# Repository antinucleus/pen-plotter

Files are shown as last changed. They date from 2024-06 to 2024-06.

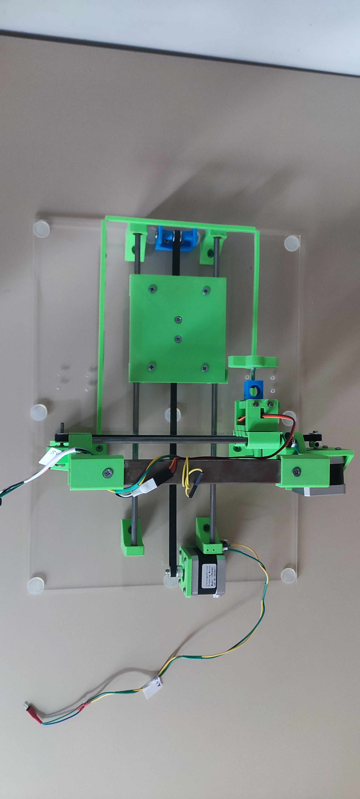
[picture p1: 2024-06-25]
Mechanical Design/Media/Realized Machine Photos/top.jpg

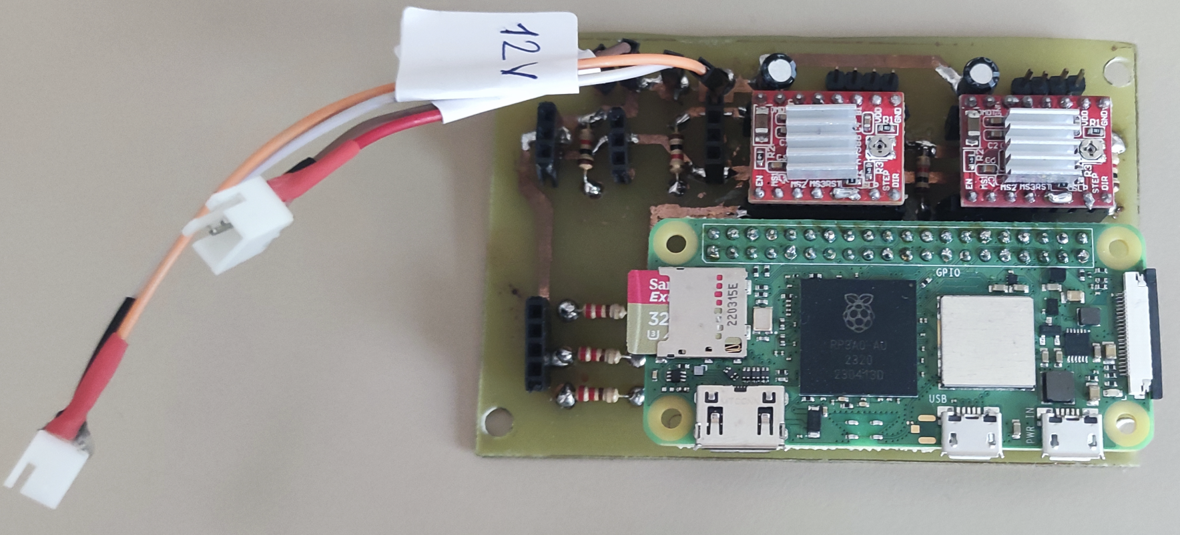
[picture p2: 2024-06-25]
Electrical Design/Media/Realized Photos/realized.png

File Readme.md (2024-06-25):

# GRADUATION THESIS

This repository explains the project i made for my mechatronics engineering graduation thesis. This README file contains general project information. For detailed information, please refer to the mechanical, electronic, and software folders.

## Table of Contents

- [Introduction](#introduction)
- [Demo](#demo)
- [Mehatronic System Design Report](#msd-report)
- [Final Report](#final-report)
- [Contact](#contact)

## Introduction

The graduation thesis project is a pen plotter machine. All mechanical, electronic, and software sections of this project have been created from scratch. Each section has its own folder. You can see the features and known shortcomings of the project in the README file of each section. For details, you can review the reports in the `reports` folder located in the root directory.

## Demo

<h4 align="center">
  Watch Demo Video on Youtube
</h4>

Watch the video (https://www.youtube.com/watch?v=F13d5m1M79A)

## MSD Report

You can access the `mechatonic system design` report from the link below.

MSD Report Link: [Mechatronic System Design Report](https://github.com/antinucleus/pen-plotter/blob/main/Reports/MST-Report.pdf)

## Final Report

Due to the time problem during the project, there are some missing and unformatted sections in the final report. You can access the `final report` from the link below.

Final Report Link: [Final Report](https://github.com/antinucleus/pen-plotter/blob/main/Reports/Final-Report.pdf)

## Contact

Ömer Faruk Bağcı - [omerfarukbagci@antinucleus.dev](mailto:omerfarukbagci@antinucleus.dev)

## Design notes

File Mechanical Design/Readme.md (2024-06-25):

# MECHANICAL DESIGN

You can find the STL files in the STL folder in this directory. For details, you can review the reports in the `reports` folder located in the root directory.

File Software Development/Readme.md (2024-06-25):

# SOFTWARE DEVELOPMENT

In this section, you can examine how the software side of the project works.

## Table of Contents

- [Introduction](#introduction)
- [How It Works](#how-it-works)

## How It Works ?

The entire control of the plotter machine is managed by a **Raspberry Pi Zero 2W** board and a mobile application that controls it. Two main programs run on the Raspberry Pi: the `server` and the `hardware control program (the hardware control program is named Raspi Hardware Controller)`. These programs are run by linux services that start themselves after the **Raspberry Pi OS** boots.

### Raspberry Pi Zero 2W Side

The folder structure for the two main programs running on the Raspberry Pi is as follows:

```bash
|___ PlotterController
     |
     |___ plotter-express-server
     |
     |___ embedded
```

- The `plotter-express-server` directory contains the server program that facilitates communication between the `mobile application` and the `Raspi Hardware Controller`. This server is written with `express.js`.

- The `embedded` directory contains the program written in `cpp` that controls the hardware (stepper motors, servo motors, limit switches...) which I have named `Raspi Hardware Controller`.

#### Linux Services

The above two programs are automatically started by Linux services after the **Raspberry Pi OS** (installed on the Raspberry Pi Zero 2W) boots. These Linux services are as follows:

- The following linux service runs the server written in `express.js`.

```sh
[Unit]
Description=Server Controller Service
After=multi-user.target

[Service]
Type=idle
ExecStart=/usr/bin/node /home/oxygen/Desktop/PlotterController/plotter-express-server/index.js

[Install]
WantedBy=multi-user.target
```

- The other Linux service runs the `Raspi Hardware Controller`.

```sh
[Unit]
Description=Raspi Hardware Controller
After=multi-user.target

[Service]
Type=idle
ExecStart=/home/oxygen/Desktop/PlotterController/embedded/run

[Install]
WantedBy=multi-user.target
```

#### Server

Server program project link: https://github.com/antinucleus/plotter-express-server

#### Hardware Controller Program

Raspi hardware controller project link: https://github.com/antinucleus/plotter-embedded-controller

### Mobile Application Side

The mobile application is built with `expo`. With the mobile application, the plotter machine can be used in manual mode or to print desired image files. You can click on the following link to access the mobile application project.

Mobile application project link: https://github.com/antinucleus/plotter-mobile-application

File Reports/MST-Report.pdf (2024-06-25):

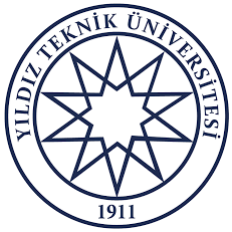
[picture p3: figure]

YILDIZ TECHNICAL UNIVERSITY

PEN PLOTTER

Ömer Faruk Bağcı

MECHATRONICS SYSTEM DESIGN REPORT

Project Advisor: Assoc. Prof. Haydar Livatyalı

ISTANBUL, 2023

Pen Plotter | Rev 2.1

CONTENTS

REVISION HISTORY | V

REVISION HISTORY

Date | Rev. No | Definition | Author(s)
23/12/2023 | 1.0 | Report Beginning | Ömer Faruk Bağcı
24/12/2023 | 1.1 | Mechanical Design and Torque Calculation was Added | Ömer Faruk Bağcı
25/12/2023 | 1.2 | Abstract, Project Definition, Aim, Scope, Literature Analysis was Added. | Ömer Faruk Bağcı
26/12/2023 | 1.3 | Power Consumption Calculation, Software was Added | Ömer Faruk Bağcı
27/12/2023 | 1.4 | Sensors, Project Management, Technical Requirements Analysis was Added. | Ömer Faruk Bağcı
28/12/2023 | 1.5 | The Report was Edited Together According to Its Integrity. | Ömer Faruk Bağcı
30/12/2023 | 1.6 | Content, Figure List, Table List was Created. Report Page Layout was Edited. | Ömer Faruk Bağcı
31/12/2023 | 1.7 | Motor Selection was Added | Ömer Faruk Bağcı
02/01/2024 | 1.8 | Equations were Named. | Ömer Faruk Bağcı
05/01/2024 | 2.0 | Final Preliminary Report was Completed. | Ömer Faruk Bağcı
11/01/2024 | 2.1 | Changed Titles and Typos were Fixed. | Ömer Faruk Bağcı

SYMBOL LIST

a: Acceleration

W: Weigℎt

N: Newton

Amps: Amper × Second

V: Volt

A: Amper

ℎ: ℎour

Wℎ: Watt × Hour

π: 3.14

LIST OF FIGURES

LIST OF TABLES

ABSTRACT

Ink or laser for transferring digital drawings or writings onto a sheet of paper printers are

used. In some cases, this information is not stored on paper or in other ways. It must be

transferred to the surface. In cartography, technical training is required to draw detailed maps

for drawing or drawing electronic circuits on PCBs (Printed Circuit Boards) Ink or laser

printers are not useful when necessary. For example, to transfer an electronic circuit drawing

onto a PCB, ink or laser It must be printed on wax paper using a printer. Then, the circuit

drawing on paper is transferred to the PCB using heat. However, while the drawing is

transferred onto the PCB using heat, the ink in some areas may not completely transfer to the

PCB or the paper may tear. A pen plotter device can be used to solve the problems in this

example. With the pen plotter device, drawings can be made on different surfaces easily and

with high precision transferable.

There are two types of plotter machines. One of them is electrostatic plotter another one is

pen plotter. We decided to design pen plotter becuase of our project requirements. Raspberry

pi zero 2w single board computer will be used in plotter motion control and receiving data

that will be plotted. In the motor motion side, Nema 17 step motor and Sg90 servo motor will

be used. Our machine will be controlled with mobile or desktop application remotely. For

these applications we use JavaScript and TypeScript languages. On the single board computer

side we use JavaScript and C languages.

1. PROJECT DESCRIPTION

This project delves into the development and implementation of a Raspberry Pi Zero 2W-

controlled Pen Plotter, designed to merge artistic creativity with technological precision. The

project incorporates a 2-step motor for bed movement, a servo for pen adjustment, and

operates on a 12V power supply. Its control mechanism allows users to interact with the

machine effortlessly through a mobile or desktop application via wifi, offering a seamless and

user-friendly experience. The mechanical aspect of the plotter employs a belt and pulley

system for optimal movement precision.

2. PROJECT OBJECTIVES

The aims of the project can be summarized as follows.

- To transfer data using wireless communication technology
- Designing a simple and understandable interface
- To use current technological opportunities effectively
- Creating high precise plotting machine
- To support various surfaces for plotting
- Creating affordable machine by amateurs

3. PROJECT SCOPE

Pen plotters are technology products that enable drawing with high precission on different

surfaces, which are becoming widespread in the market, and are used by businesses in

advertising and brochure printing. We aim for amateur-level businesses with wireless use and

a quality interface design. Since we aim for amateur users, we aimed for ease at every stage of

the product. It can be used in different studies thanks to its easy installation, easy use,

affordable maintenance costs and support of different file types.

4. LITERATURE ANALYSIS

The iDraw 2.0 features a working area of 219 mm x 297 mm and supports file formats such as

JPEG, PNG, BMP, and SVG. Weighing 5kg, it employs a Cartesian Gantry motion system

and is housed in an open case frame.

With a larger working area of 29 7mm x 420 mm, the iDraw A3 also supports JPEG, PNG,

BMP, and SVG file formats. Weighing 2.5kg, it shares the Cartesian Gantry motion system

and open case frame design with iDraw 2.0.

The AxiDraw V3 offers a working area identical to iDraw 2.0 (219 mm x 297 mm) and

exclusively supports SVG files. Weighing 2.2kg, it utilizes a Cartesian Gantry motion system

and an open case frame.

Featuring a smaller working area of 60 mm x 90 mm, Line-us supports files through its

dedicated app. The weight is undefined, and it stands out with a SCARA motion system

within an open case frame.

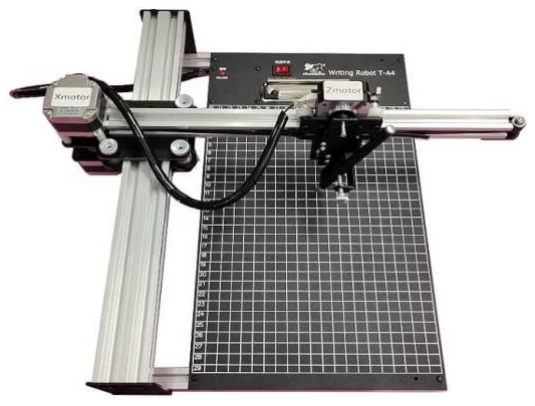
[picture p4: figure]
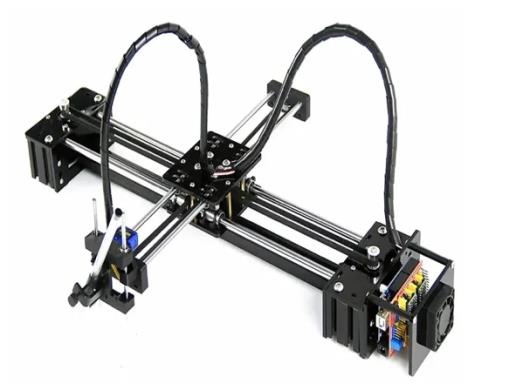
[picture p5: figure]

Figure 1 – iDraw 2.0 | Figure 2 – iDraw A3

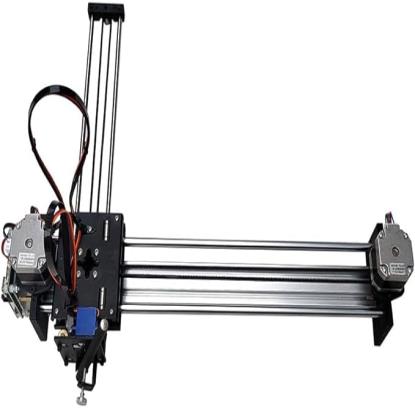
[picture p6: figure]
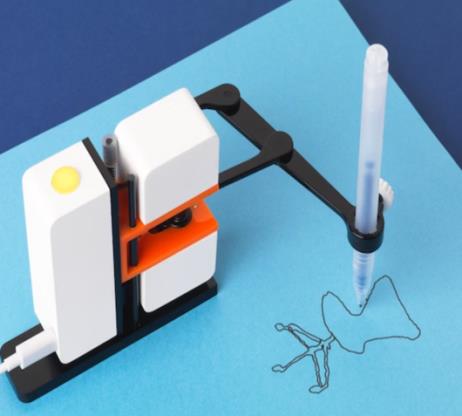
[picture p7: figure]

Figure 3 – Axi Draw V3 | Figure 4 – Line-us

This detailed comparison provides a comprehensive overview of the specifications for each

pen plotter, aiding in a nuanced decision based on individual preferences and requirements.

The technical specifications of the pen plotters are given in Table 1.

Spec. | iDraw 2.0 | iDraw A3 | Axi Draw V3 | Line - us
Working Area (mm x mm) | 219 x 297 | 297 x 420 | 219 x 297 | 60 x 90
File Formats | JPEG,PNG,BMP,SVG | JPEG,PNG,BMP,SVG | SVG | Runs through Line-us app
Weight (kg) | 5 | 2.5 | 2.2 | Undefined
Motion Type | Cartesian Gantry System | Cartesian Gantry System | Cartesian Gantry System | SCARA System
Frame Type | Open Case | Open Case | Open Case | Open Case

Table 1 – Pen Plotter Comparison

5. PROJECT BLACK BOX DIAGRAM

The black box diagram of the system is as follows. The desired plotting part is given as an

input to the system. In turn, the part in which the last desired plotting was made is taken as an

output by going through the operations in the box.

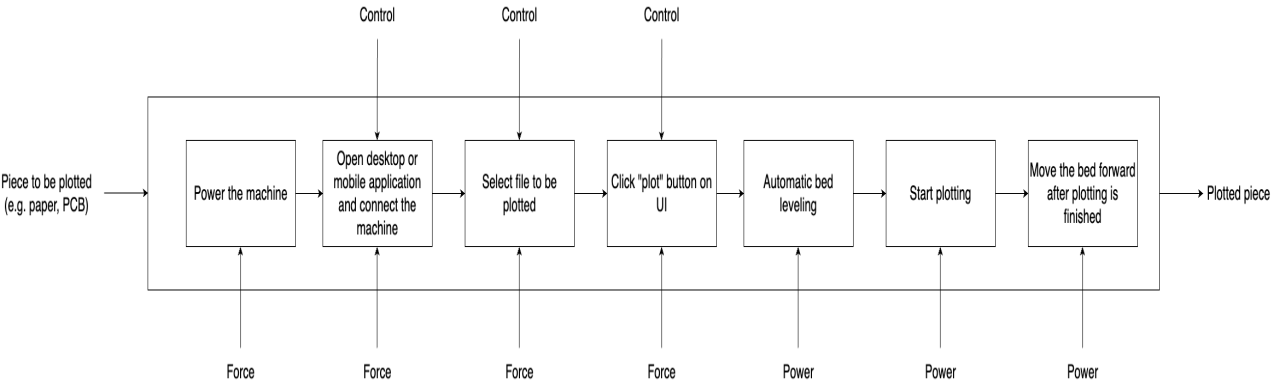
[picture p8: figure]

Figure 5 – Black Box Diagram

6. PROJECT NEEDS

While determining the project needs, a study was conducted on what advantages the products

have or what problems they have in the literature research. In the fields of architecture,

cartography and education, a study was conducted on which features our project can compete

with other products in the market. In order for our product to be used in the field of education,

our project should be reasonably priced compared to other products in the market. For use in

areas such as cartography, architecture, it should be a machine with high precision. Project

needs are sorted by their importance. You can see all the project needs below in Table 2.

No | Need | Importance
1 | Lightweight | 5
2 | Can be controlled remotely without requiring a special device | 5
3 | Lasts a long time | 5
4 | Support different size of pens | 5
5 | High moving precision | 5

6 | Affordable for amateurs | 4
7 | Plug and play | 4
8 | No sharp corners | 4
9 | Adjustable speed | 4
10 | Sensitivity adjustment | 3
11 | Easy to assemble | 3
12 | Easy to install | 3
13 | Wide plotting area | 3
14 | Plot from various files | 3
15 | Can be easily maintained | 2

Table 2 – Project Needs

7. PROJECT REQUIREMENTS

The objective tree for the product has been created according to the project needs.

Accordingly, the lens tree is divided into 3 main parts. These are quality, cost-effectiveness,

and what needs to be achieved.

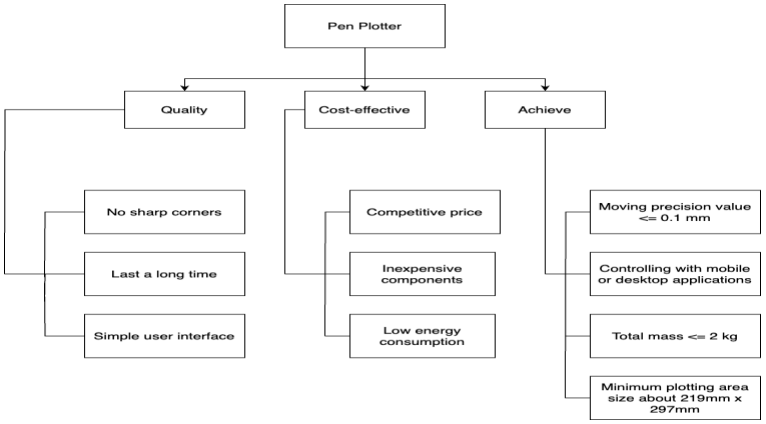
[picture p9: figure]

Figure 6 – Objective Tree

Project requirements created according to the project needs and objective tree. The items on

the project needs list are not engineering terms so, we have listed the items in the project

requirements in a way that complies with engineering terms. You can see the project

requirements in Table 3 below.

Metric No. | Need Nos. | Metrics | Importance | Unit
1 | 1 | Total mass | 5 | kg
2 | 2 | Controlling with mobile and desktop applications | 5 | List
3 | 3 | MTTF value | 5 | hr
4 | 4 | Pen gripper diameter | 5 | mm
5 | 4 | Pen height | 5 | mm
6 | 4 | Pen diameter | 5 | mm
7 | 9, 5 | Speed of base plate | 4 | mm/s
8 | 9, 5 | Step count per full revolution | 4 | steps/rev
9 | 6 | Unit product cost | 4 | $
10 | 7 | No complex user interface | 4 | Subj.
11 | 7 | Power on/off with one mechanical button | 4 | s
12 | 8 | Buck edge radius | 4 | mm
13 | 9, 10 | Microstepping range | 3 | List
14 | 11, 12, 15 | Time to assemble/disassemble | 3 | s
15 | 13 | Area of plotting base | 3 | mm^2
16 | 14 | Support common document types | 3 | List

Table 3 – Project Requirements

8. QUALITY FUNCTION DEPLOYMENT OF THE PROJECT

The quality function diagram of the project is given below. The diagram has been prepared

according to the needs and requirements of the project. iDraw 2.0, iDraw A3, axiDraw V3,

and line-us have been added as competing products.

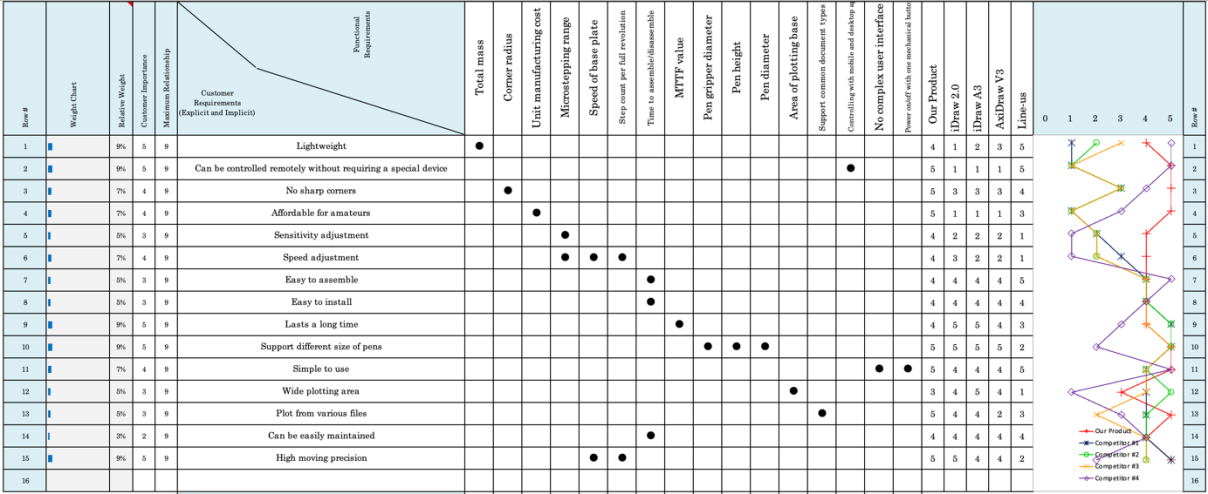
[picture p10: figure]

Figure 7 – Quality Function Diagram of The Project

9. PROJECT SPECIFICATIONS

The project requirements were created using engineering terms, but the values of these terms

need to be determined. While determining these values, literature research was conducted,

and an attempt was made to determine the ideal value. Marginal values were also determined

based on ideal values. Some project requirements were left blank because the ideal values of

the terms could not be found. You can see all the project specifications below in Table 4.

No | Need Nos. | Metrics | Imp. | Unit | Margianal Value | Ideal Value
1 | 1 | Total mass | 5 | kg | < 2 | < 1.5
2 | 2 | Controlling with mobile and desktop applications | 5 | List | Android, Ios, macOs, Windows | Android, Ios, macOs, Windows
3 | 3 | MTTF value | 5 | hr | 20000 - 100000 | 25000 - 1300000
4 | 4 | Pen gripper diameter | 5 | mm | - | -

5 | 4 | Pen height | 5 | mm | - | -
6 | 4 | Pen diameter | 5 | mm | 8 - 12 | 6 - 20
7 | 9, 5 | Speed of base plate | 4 | mm/s | 0.1 - 3 | 0.01 – 5
8 | 9, 5 | Step count per full revolution | 4 | steps/rev | 200 - 3200 | 64 - 6400
9 | 6 | Unit product cost | 4 | $ | < 100 | < 80
10 | 7 | No complex user interface | 4 | Subj. | - | -
11 | 7 | Power on/off with one mechanical button | 4 | s | - | -
12 | 8 | Buck edge radius | 4 | mm | - | -
13 | 9, 10 | Microstepping range | 3 | List | 1, 4, 8, 16 | 1, 4, 8, 16, 32, 64
14 11, | 12, 15 | Time to assemble/disassemble | 3 | s | - | -
15 | 13 | Area of plotting base | 3 | mm^2 | 148 x 210 | 219 x 297
16 | 14 | Support common document types | 3 | List | JPEG, PNG, SVG | JPEG, PNG, SVG, BMP

Table 4 – Project Specifications

10. SYSTEM ARCHITECTURE

As seen in the below, the pen plotter machine consists of two subsystems. The first of these

systems is the plotter machine and the other is the pen plotter machine control application.

The file you want to plot is selected using the control application. The selected file is sent to

the plotter machine and the drawing process is started on the part placed on the surface of the

machine.

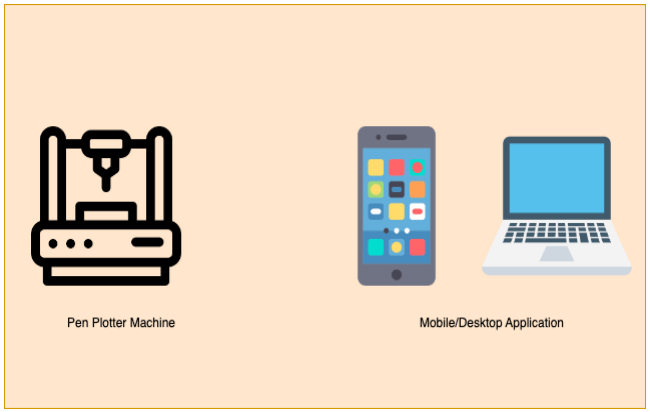
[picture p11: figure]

Figure 8 – Pen Plotter Subsystems

Whichever part we want to print on is placed in the device. The file we want to plot is sent via

raspberry wifi using the mobile and desktop application. In Raspberry, this file is converted to

g-code. After the G-code generation, the necessary signals are sent from the drivers

depending on the g-code to the stepper and servo motors. After the G-code processing is

completed, the desired file is plotted on the part placed in the machine. You can see the

general system architecture in Figure 9.

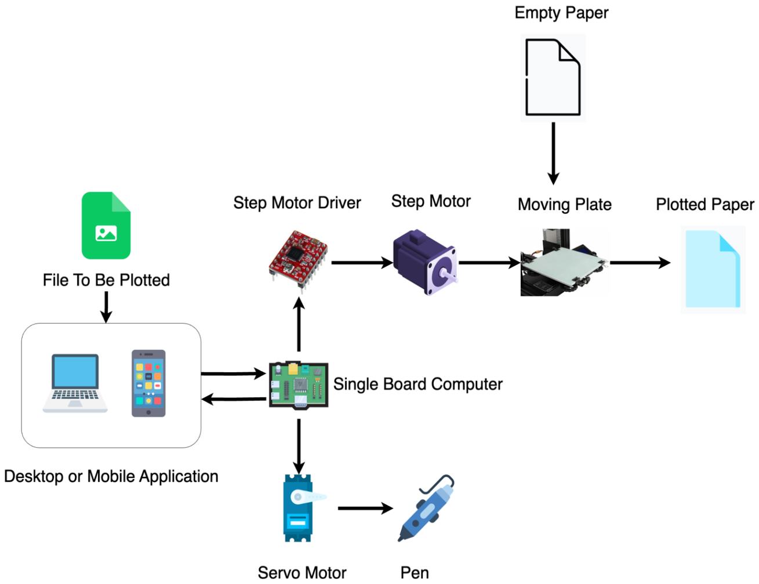
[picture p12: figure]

Figure 9 – General System Architecture

11. DESIGN

Pen plotter machine is divided into two subsystems as mobile/desktop application and

mechanical part. In the mechanical part, 2 stepper motors were used to move the pen in the

desired directions in the x and y directions. The stepper motors are mounted on the bed and

pen gripper with a belt system. The belts, on the other hand, receive the movement from the

step motor with a pulley. The belts are again supported by a pulley. The pen gripper and the

bed both slide on two axles. A servo motor is used to move the pen up and down. Preliminary

design can be seen in Figure 10.

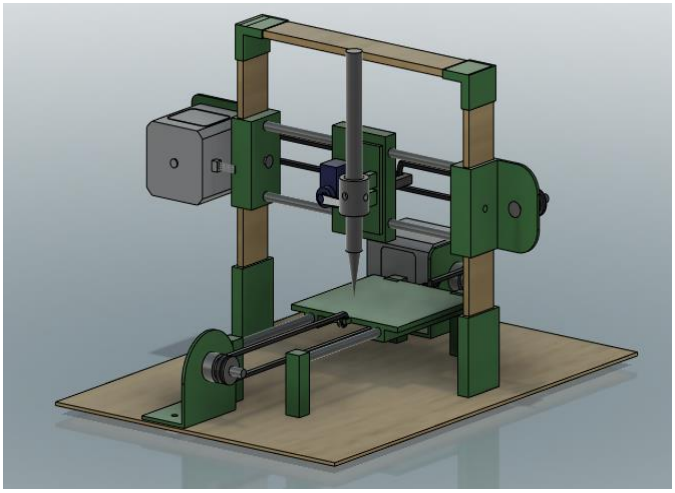
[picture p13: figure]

Figure 10 – Preliminary Design

11.1 Body Design

There are 3 common type for body design based on motion type. One of them is cartesian

gantry system, another one is scara system and the last one is cartesian system. We decided to

use cartesian system, so our design for this motion type is open frame.

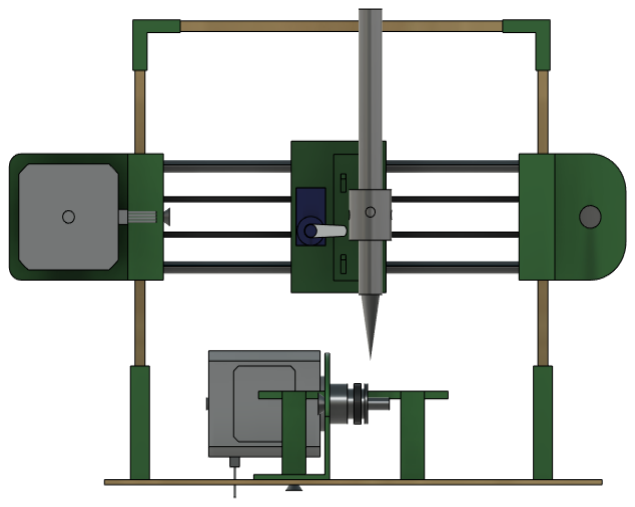
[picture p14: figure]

Figure 11 – Cartesian Open Frame Design

11.2 Mechanical Calculations

We determined sensitivity of the plotter machine as 0.01 mm. The operation of the machine

with this precision does not depend only on the step motor. Since the machine will move with

a belt and pulley system, this sensitivity depends on the pulley, motor angle and

microstepping resolution of step driver. When we investigate the stepper motors sold on the

market, the step angles range from 0.9° to 5.625°. There are many types of motors on the

market for 1.8° step angle. Because of the easy access and stability we selected Nema17

HS4401 step motor. This step motor has 1.8° step angle. We selected the belt that is GT2

timing belt which has width of 6 mm and GT2 16 teeth pulley. Tooth pitch of the pulley is 2

mm.

Specifications | Value
Number of teeth | 16
Pitch | 2 mm
Circumference | 16 x 2 = 32 mm

Table 5 – Pulley Specifications

The belt will move at a distance equivalent to 32 mm per rotation. Motor takes 1.8° per step.

One step will move plotter by a distance of (32 mm/360°) x 1.8° = 0.16 mm. For 0.01 mm

distance we selected the motor driver which has 1/16 microstepping resolution. Using 1/16 microstepping operation one step will become (1.8°/16) = 0.1125°. One step will

move plotter by a distance of 32mm/360° x 0.1125° = 0.01mm.

11.3 Torque Calculation

We have to check torque of the motor is enough for pencil gripper mechanism and bed.

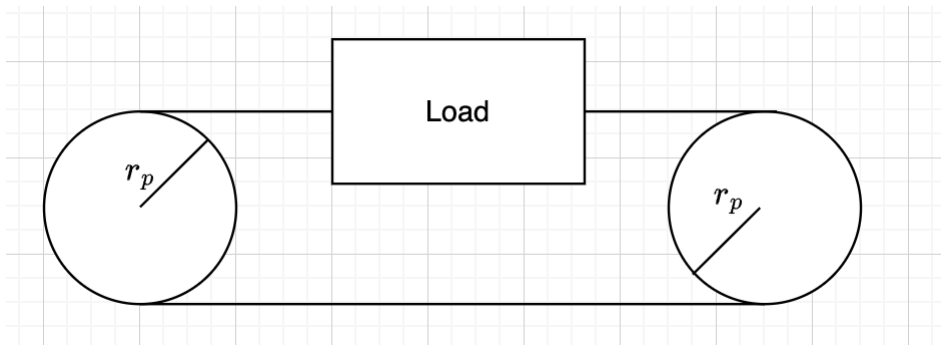
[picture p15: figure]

Figure 12 – Pulley and Load

Required information are listed Table 6 below.

Specification | Value
) Load weight ( ml | 300g = 300x10⁻³kg
Belt weight ( mb ) | 12g = 12x10⁻³kg
Pulley weight ( mp ) | 5g = 5x10⁻³kg
Inertia of the motor ( Jm ) | 54gcm² = 5.4x10⁻⁶kgm²
Outer diameter of the pulley ( ro ) | 12mm = 12x10⁻³m
Inner diameter of the pulley ( ri ) | 5mm = 5x10⁻³m

Table 6 – Mechanical Component Specifications

First calculate the inertia of the pulley.

Jp =

1
2

mp(ro

2 + ri

2
) | (Eq. 11.1)

where,

Jp ≫ Inertia of tℎe pulley

mp ≫ Weigℎt of tℎe pulley

ro ≫ Outer diameter of tℎe pulley

ri ≫ Inner diameter of tℎe pulley

Jp =

1
2

x(5x10⁻³

)(12² + 5

2

)x10⁻⁶ = 0.423 x10⁻⁶ kgm² (Eq. 11.2)

For load calculation there are two load for two belt system pen gripper section and bed.

Because of the weight of the bed is higher than pen gripper, we selected load as weight of the

bed. Also extra weight is included that is weight of the belt.

Jl = (mb + ml

)x(ro

2
) | (Eq. 11.3)

where,

Jl ≫ Inertia of tℎe load

mb ≫ Weigℎt of tℎe belt

ml ≫ Weigℎt of tℎe load

ro ≫ Outer diameter of tℎe pulley

Jl = (12x10⁻³ + 300x10⁻³

)x(12²

)x10⁻⁶

= 44.928x10⁻⁶ kgm²

(Eq. 11.4)

Now, we can calculate total inertia of the system. Total inertia of the system summation of the

inertia of the motor, inertia of the pulleys and inertia of the load.

Jt = Jm + Jp1 + Jp2 + Jl | (Eq. 11.5)

where,

Jt ≫ Total inertia of tℎe system

Jm ≫ Inertia of tℎe motor

Jp1 ≫ Inertia of tℎe pulley 1

Jp2 ≫ Inertia of tℎe pulley 2

Jl ≫ Inertia of tℎe load

Jt = (5.4 + 0.423 + 0.423 + 44.928)x10⁻⁶

= 51.174x10⁻⁶kgm²

(Eq. 11.6)

We can calculate the required torque with total inertia and angular acceleration of the motor.

Low angular acceleration is enough for this machine. So, it is selected 0.1

rad
s

2

. Using

equation below we can calculate the torque value.

Tacc = Jt x α | (Eq. 11.7)

where,

Tacc ≫ Acceleration torque

Jt ≫ Total inertia of tℎe system
α ≫ Angular acceleration of tℎe motor

Tacc = (51.174x10⁻⁶

)x0.1 = 5.1174x10⁻⁶ Nm | (Eq. 11.8)

The detent torque (acceleration torque) of the motor is given that 2.2 N.cm as maximum. Which is equal to 22x10⁻³ Nm. Our calculated torque value is so smaller than the maximum

torque of the motor, so this motor can be used in this project.

12. MOTOR SELECTION

Nema17 HS4401 step motor specifications required for our project are listed in the Table 7

below.

Specification | Value | Image
Step Angle ( θs ) | 200
Maximum Current ( Imax ) | 1.7 A
Inductance ( L ) | 2.8 mH
Inertia of the motor ( Jm ) | 54gcm²

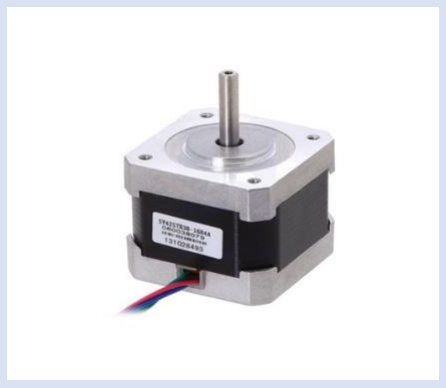
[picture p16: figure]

Table 7 – Nema17 HS4401 Specifications

13. ELECTRICAL SYSTEM DESIGN

The electrical drive system of the plotter will consist of three main systems. These are DC

step motor, step motor driver and power supply respectively. The step motor configuration of

the machine will be selected in such a way that it can move the base plate with determined

speed that specified in the technical requirements. The step motor driver will be selected

according to the technical specifications of the step motor.

In the circuit below, there are two step motors, two step motors driver, two limit switches, tow

pull-down resistors, one signel board computer and one servo motor. Step motor drivers are

powered by 5 volts and its motor voltage input is powered by 12 volts. Servo motor and

raspberry pi is powered by 5 volts.

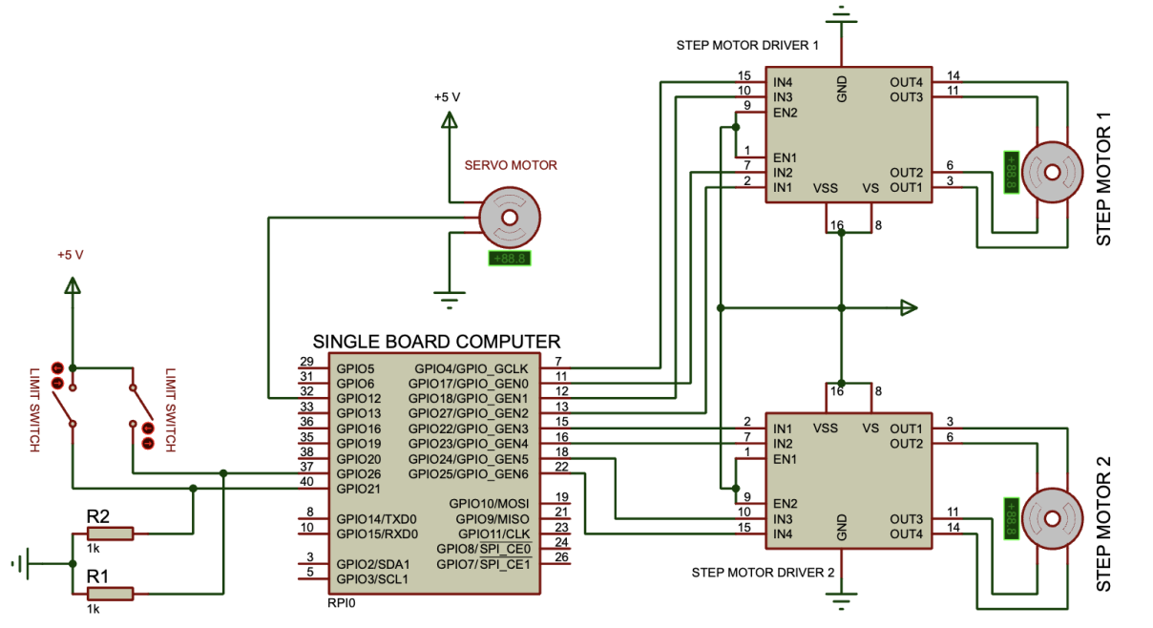
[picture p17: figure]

Figure 13 – Electrical Circuit of The Plotter Machine

14. POWER CALCULATION

It is important to know how much power the entire system consumes. Because in the

electrical circuit design part, it is necessary to make a power supply system and a power

distribution system that can provide these powers. The main consumer in the power system is

the step motors.

We will drive our stepper motors with 12 volts and the total power to be consumed in the

system is calculated as 44.3 watts. A device with a 12-volt 4 ampere can be selected as the

power supply, but a power supply with a 12-volt 5 ampere specification will be selected so

that there are no glitches in the system.

No | Component | Voltage | Ampere (A) | Power (W)
1 | Raspberry pi zero 2w | 5 | 0,120 | 0,7
2 | Nema17 HS4401 - 1 | 12 | 1.7 | 20,4
3 | Nema17 HS4401 - 2 | 12 | 1.7 | 20,4
4 | Sg90 | 5 | 0,550 | 2,75
5 | Step motor driver | 5 | 0,008 | 0,04
| Total | | | 44,3

Table 8 – Power Consumption of The Components

15. STEP MOTOR DRIVER SELECTION

According to mechanical calculation section, microstepping resolution of the driver must be

minimum 1/16. In market we found a4988 step motor driver. This step motor driver can

supply 2A output. Nema17 HS4401 stepper motor has maximum 1.7A and this driver can be

work at 8-35 voltage range. Also we can use this driver with 1/16 microstepping resolution.

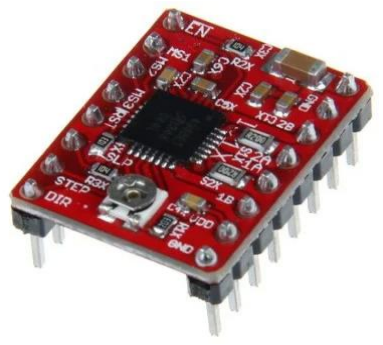
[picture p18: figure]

Figure 14 – A4988 Step Motor Driver

16. SENSORS

The sensors to be used in the project were selected in line with the literature research and the

technical requirements of the project. Accordingly, only one sensor is need for our project that

is limit switch. We use limit switch for determining that the base plat is collide with

boundiries.

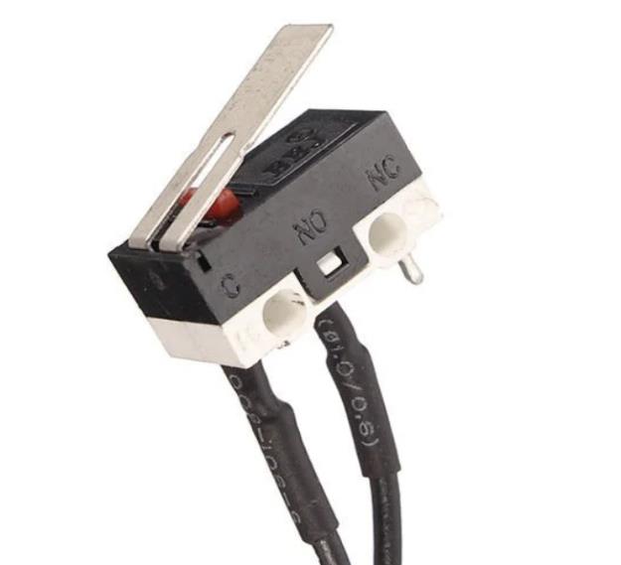
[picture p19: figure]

Figure 15 – Limit Switch

17. COMMUNICATION SYSTEM

In this project the pen plotter machine will communicate via wifi. Wifi module is embedded

in raspberry pi zero 2w.

Wireless communication will be made between the machine and the remote-control device

with the help of the wifi. Image transfer and other datas will be transferred in this way. Thus,

with the interface designed for the machine on the computer or mobile application, it will be

possible to follow the progress of the machine such as time, speed, coordinates, and pen

status.

18. CONTROL SYSTEM

Raspberry pi zero 2w single board computer will be used as a basis for plotter motion control

and data acquisition from sensors. Wireless data transfer to the remote-control device will be

carried out with the help of the wi-fi module. Also, file will be converted to g-code using

raspberry.

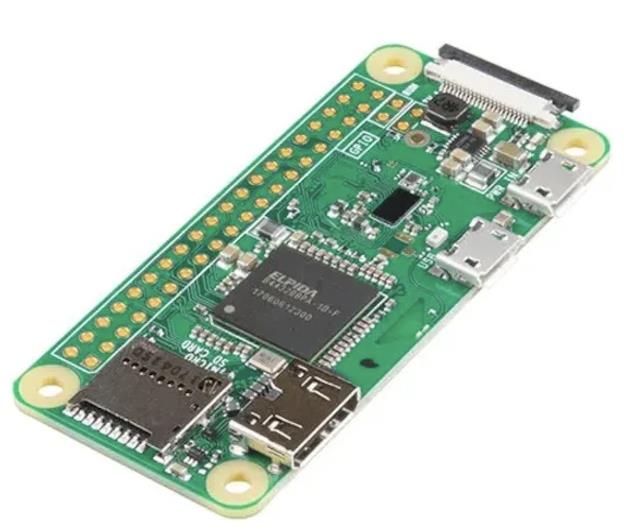
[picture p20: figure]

Figure 16 – Raspberry Pi Zero 2w

19. SOFTWARE DESIGN

Three Different software is required for the pen plotter project. These softwares are mobile

application software, desktop application software and embedded system software. Control

applications will be written for mobile and desktop that will send the necessary data to the

machine and receive the necessary information from there. On the embedded system

application side, software will be developed that will send the data from mobile or desktop

applications to the workplace and the necessary signals to the electronic parts connected to the

raspberry pi.

19.1 Mobile Application

You can see flow chart of mobile and desktop application below. First user starts the

application then connect to wifi hotspot of the plotter machine. If connection is not successful

application can not go further. After connection, user can select the file for plotting. Selected

file will send from mobile/desktop application to the plotter via wifi. If there is an error while

transferring file to the plotter or file process error, then user will be notified what is the error.

If there is no error user can start the plotting by pressing the start button.

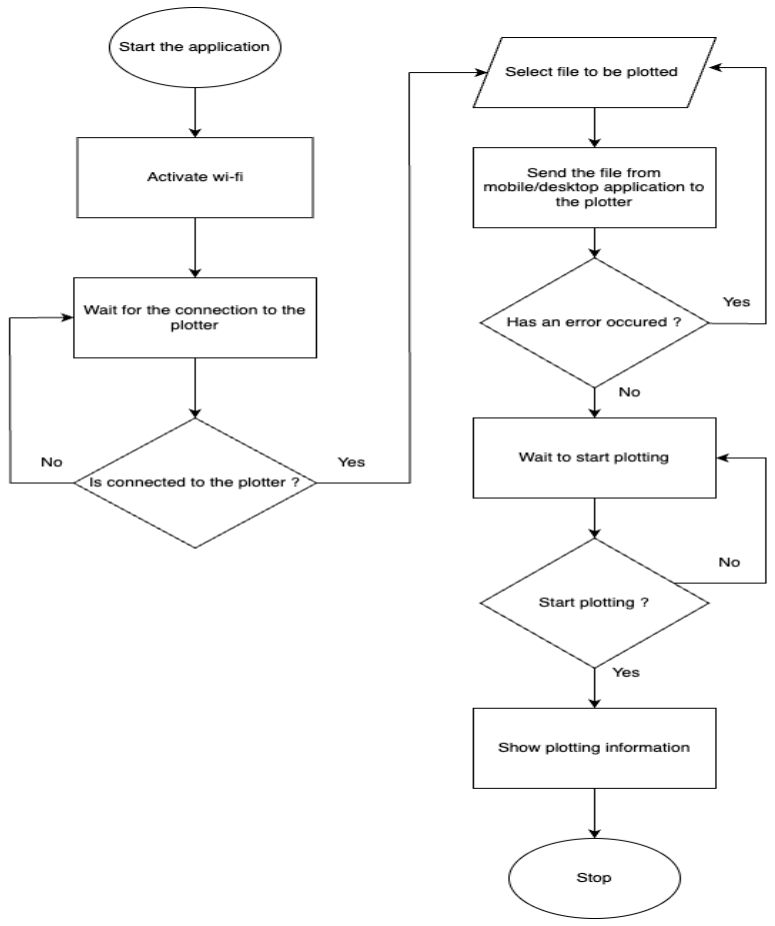
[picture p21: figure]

Figure 17 – Flow Chart of The Mobile and Desktop Applications

19.2 Mobile Application User Flow

Only user flow diagrams are shown in the application section. The final codes will be added

in the B.Ç section. All the steps of mobile application can be seen in Figure 18.

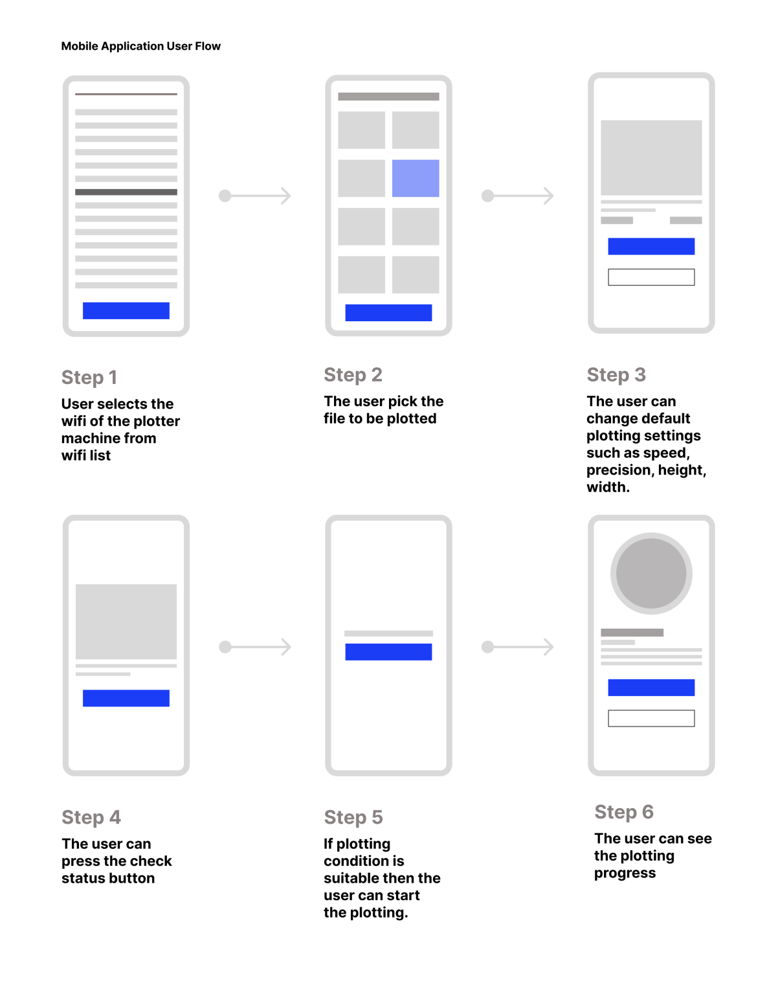
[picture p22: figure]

Figure 18 – User Flow of The Mobile Application

19.3 Desktop Application User Flow

Only user flow diagrams are shown in the application section. The final codes will be added

in the B.Ç section. All the steps of dektop application can be seen in Figure 19.

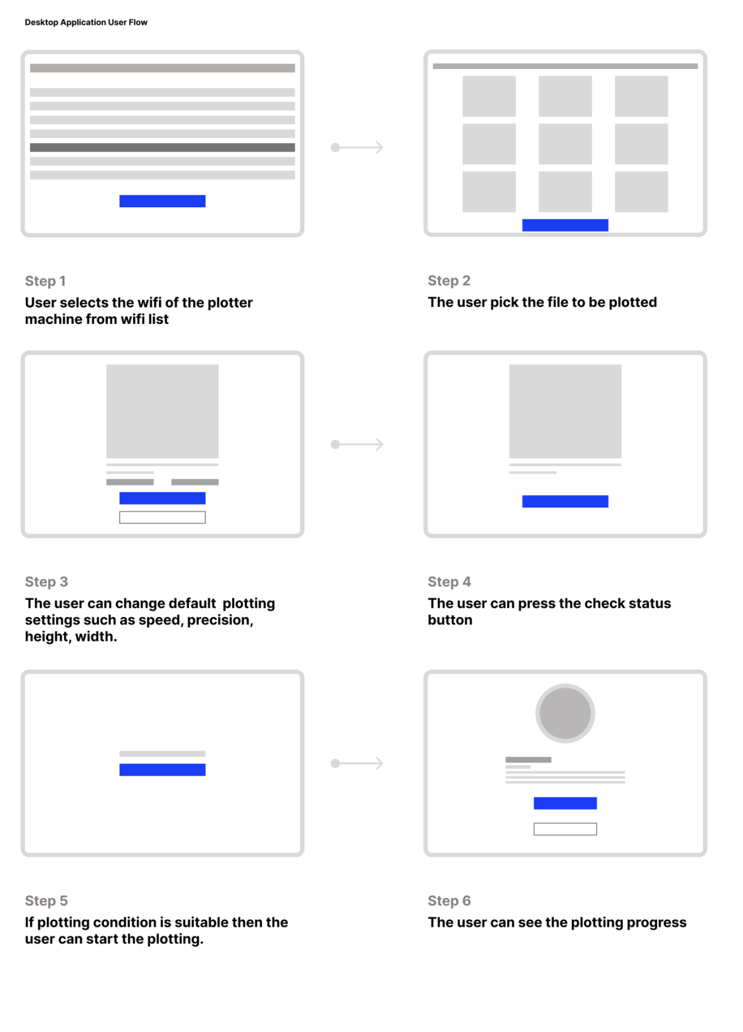
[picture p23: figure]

Figure 19 – User Flow of The Desktop Application

19.4 Plotter Software

In plotter machine side, user first start the plotter then operating system automatically activate

hotspot after the controller booted up. Also, our server software is started when controller

booted up. Server waits for mobile/desktop application connection. After device connected to

the plotter, then it will get the file from mobile/desktop application. If file type is true, then

file will be converted to g-code. If error occurred while generation of g-code, user will be

informed. Otherwise, plotter wait for start drawing command. If plotting is started machine

will plot the data to the surface. Flow chart of the plotter can be seen in below.

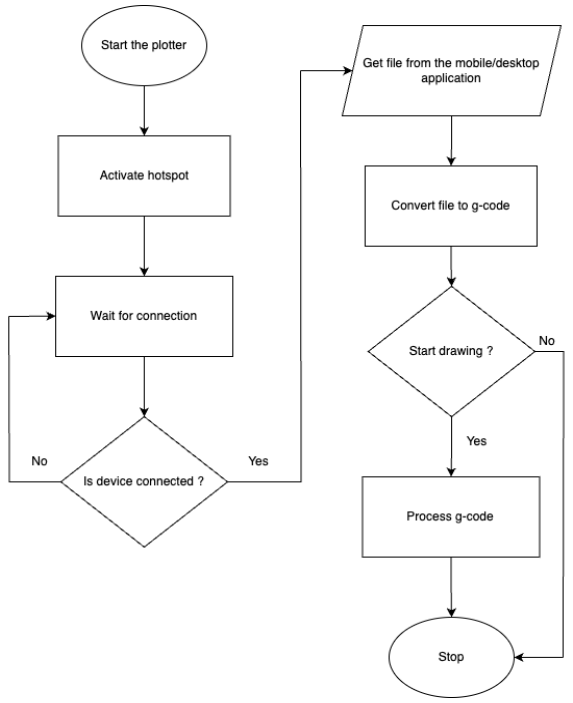
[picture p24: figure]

Figure 20 – Flow Chart of The Pen Plotter Machine

20. PROJECT MANAGEMENT

Our work schedule in the project is as follows. Responsibilities of the project team members

have been determined so that the project will be completed on time. It is aimed that the project

members make up for each other's deficiencies at the missing points in the work schedule.

No | Name and Targets of Business Packages | By Who(s) It Will Be Performed | Time Interval (10/23 – 1/2024) (4 Months)
1 | Preliminary Design: -Determining the dimensions of the pen plotter -Making mechanical analysis -Positioning of electronic equipment and motors | Ömer Faruk Bağcı | 2023 October – 2024 January
2 | Remote Control Application and Hardware Control Software Design: -Designing remote-control mobile and desktop application of pen plotter. -Designing server, images process and generating g-codes from given images for pen plotter | Ömer Faruk Bağcı | 2023 November – 2024 January
3 | Final Design and System Modeling: -Equipment selection in accordance with the preliminary design | Ömer Faruk Bağcı | 2023 December – 2024 January

Table 9 – Work Schedule

21. RISK MANAGEMENT

Some risks have been foreseen for the project. These risks and the precautions that can be

taken against these risks are shown in Table 10 below.

No | Highest Risks | Risk Management (Plan B)
1 | Mechanical failure | Conduct routine preventive maintenance. Have a service contract with a reliable maintenance provider for quick repairs. Keep a spare pen plotter on standby if possible.
2 | Data loss or corruption | Implement a robust data backup system with regular automated backups. Store backups off-site and regularly test data restoration processes.
3 | Pen malfuction | Maintain a stock of backup pens. Regularly test and replace pens and have a manual pen replacement process in case of immediate issues.
4 | Power outages | Install uninterruptible power supplies (UPS) to provide temporary power during outages. Have a backup power generator for longer outages.

Table 10 – Risk Management

22. PROJECT BUDGET

The budget request is created for five main materials and other materials. It is seen in the Table

11 below.

Components | Quantity | Unit Cost (TL) | Total Cost (TL)
Nema17 HS4401 | 2 | 250 | 500
Sg90 servo motor | 1 | 50 | 50
Raspberry pi zero 2w | 1 | 850 | 850
A4988 step motor driver | 2 | 40 | 80
Power supply | 1 | 200 | 200
Other parts | - | - | 1000
Total | - | - | 2680

Table 11 – Project Budget

SUMMARY AND CONCLUSIONS

Since initiating our project, significant progress has been made in delineating the framework

of our pen plotter machine. This involved defining the fundamental operational principles and

identifying the specific requirements of the pen plotter based on these determinations.

We decided what the basic working logic of our pen plotter would be. And in line with these

decisions, we determined the needs of our pen plotter.

Within the mechanical design domain, our focus extended to establishing the overall

structural geometry of the pen plotter machine. Consequently, we opted for an open frame and

Cartesian-type configuration. Further, we pinpointed the approximate dimensions of the

machine's body in alignment with our prototype, culminating in the creation of a three-

dimensional design for our pen plotter.

Concerning the electrical components, meticulous consideration was given to selecting

elements that align with the functionalities required by our plotter machine. The choice of a

Raspberry Pi Zero 2W as our processor, along with the identification of servo motors and step

motor drivers, exemplifies our efforts in this realm. Additionally, comprehensive decisions

were made regarding power supply configurations.

In the software arena, our initiatives commenced with the conceptualization of user flows for

both mobile and desktop applications. Simultaneously, we undertook the task of generating G-

code from input files, a pivotal aspect in our project's functionality. These collective efforts

represent crucial milestones in the development of our pen plotter machine.

REFERENCES

[1] https://www.creativebloq.com/buying-guides/best-pen-plotters
[2] https://idrawpenplotter.com/shop/ols/products/xn-idraw-pen-plotter-2-a3
[3] https://shop.pimoroni.com/products/axidraw-v3-a3?variant=32196192895059
[4] https://www.line-us.com/
[5] https://www.alldatasheet.com/datasheet-pdf/pdf/338780/ALLEGRO/A4988.html
[6] https://aus3d.com.au/products/gt2-pulley-16-teeth-5mm-bore
[7] https://www.pidramble.com/wiki/benchmarks/power-consumption
[8] https://engineering.stackexchange.com/questions/23565/determining-required-torque-for-

a-chain-and-sprocket-conveyor-belt

[9]

https://www.mechatronicscenter.com/uploads/7/5/6/2/75629763/introduction_to_motor_

sizing.pdf

[10] https://www.linearmotiontips.com/how-to-account-for-belt-and-pulley-inertia-during-

system-design/ [11] https://maker.robotistan.com/robot-kontrolculeri-sensorler/

[12] https://www.linearmotiontips.com/how-to-calculate-motor-drive-torque-for-belt-and-

pulley-systems/

[13] Ugural, Ansel C - Mechanical Design of Machine Components, Second Edition-CRC

Press (2015)

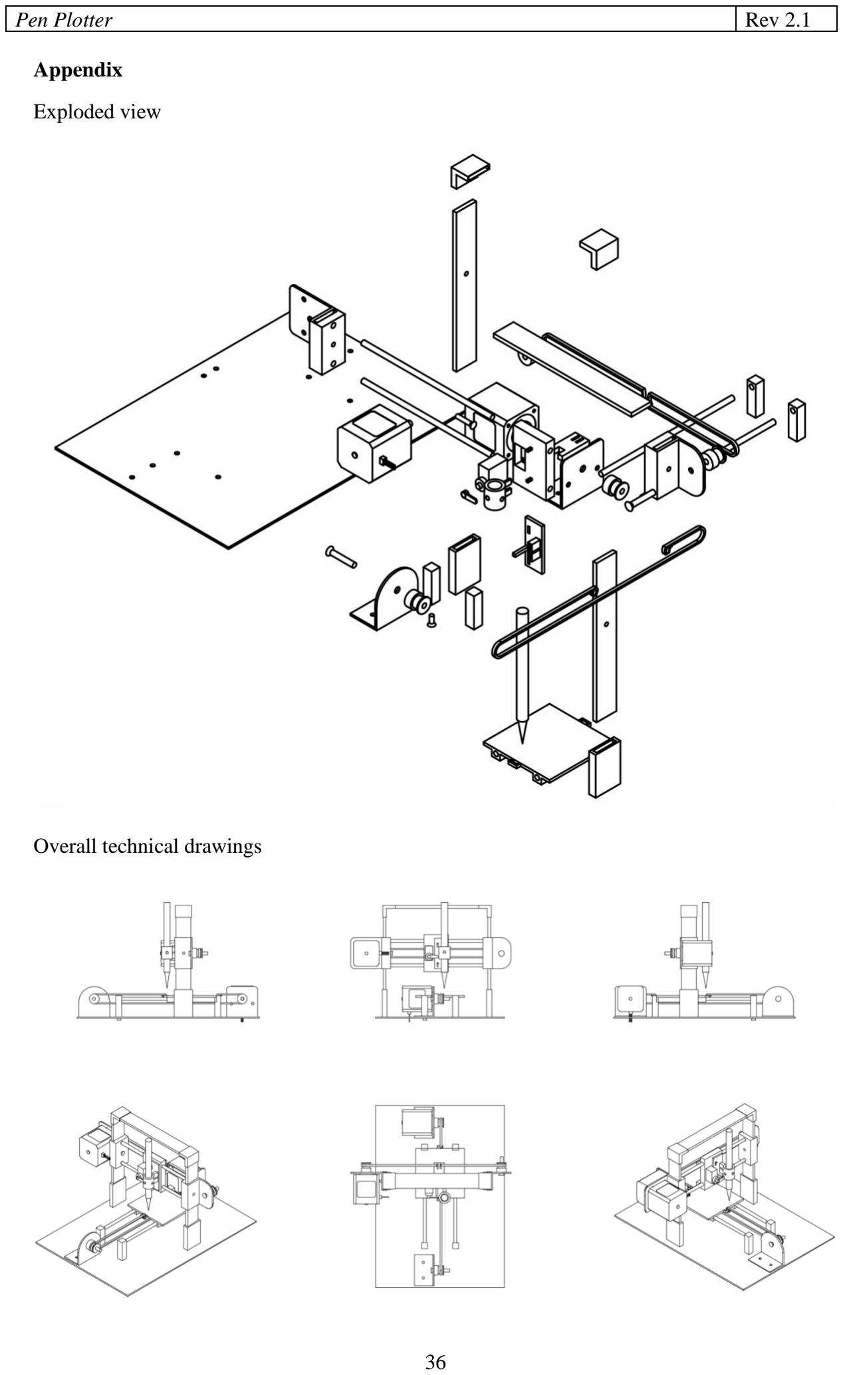
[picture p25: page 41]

Appendix

Exploded view

Overall technical drawings

Work breakdown structure (WBS)

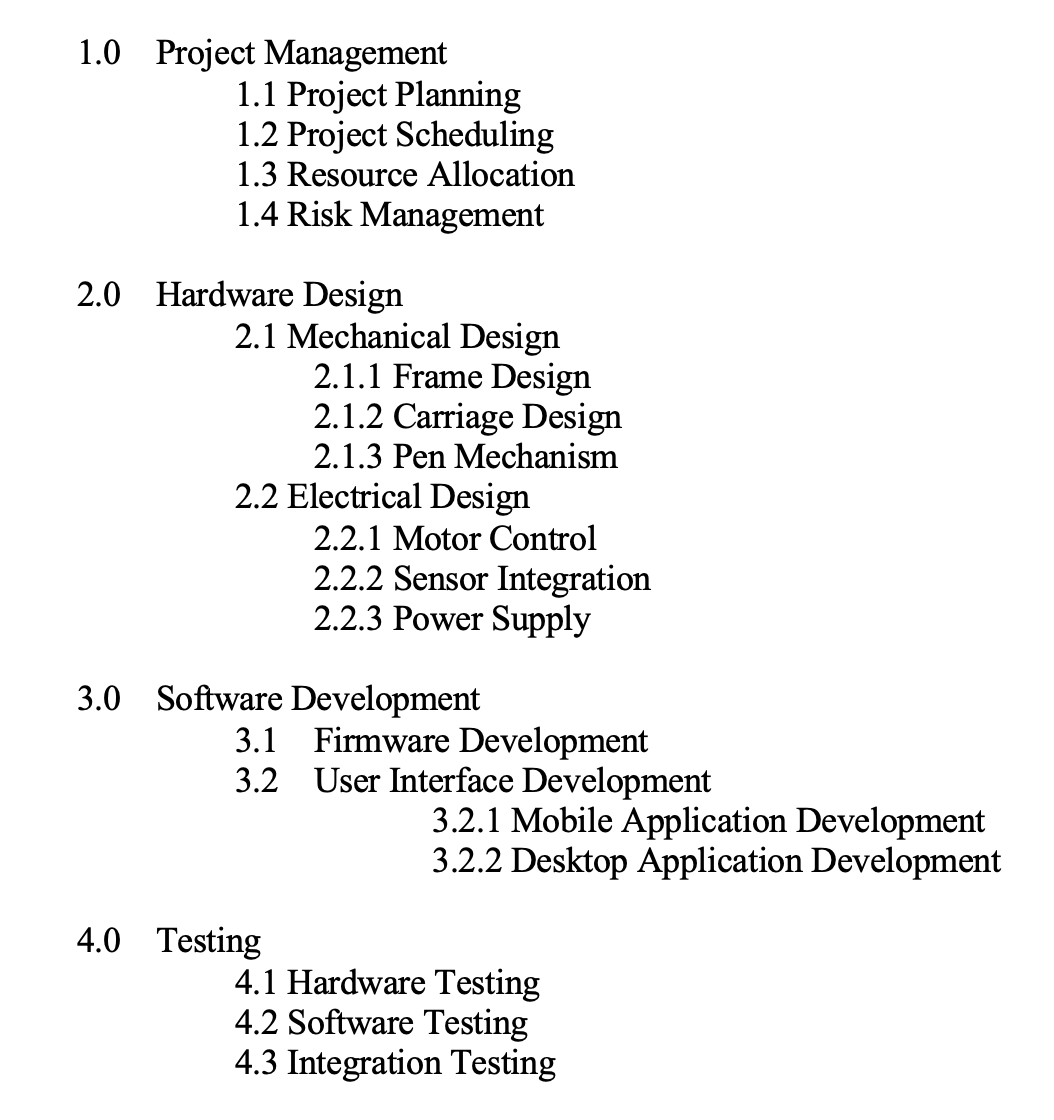
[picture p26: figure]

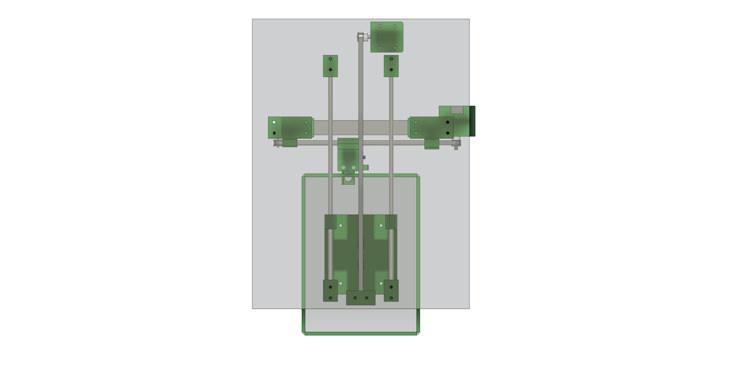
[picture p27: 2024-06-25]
Mechanical Design/Media/Fusion360 Design Images/bottom.png

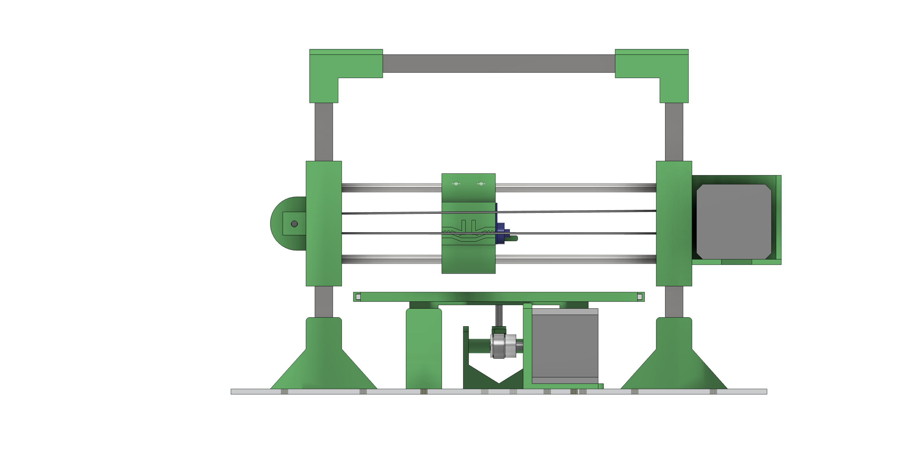
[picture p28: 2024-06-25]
Mechanical Design/Media/Fusion360 Design Images/back.png

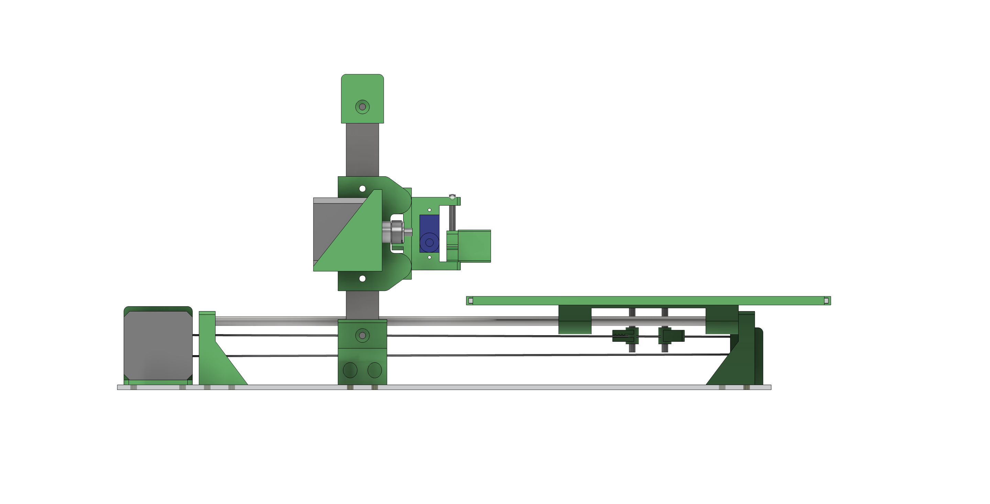
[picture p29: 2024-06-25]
Mechanical Design/Media/Fusion360 Design Images/left.png

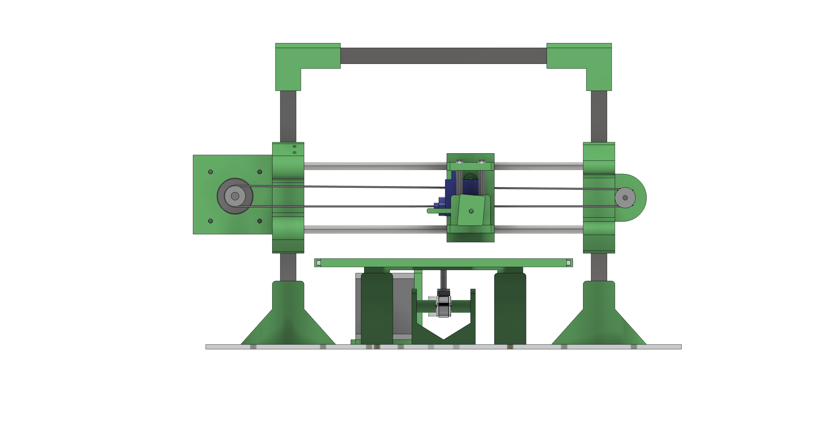
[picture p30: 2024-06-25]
Mechanical Design/Media/Fusion360 Design Images/front.png

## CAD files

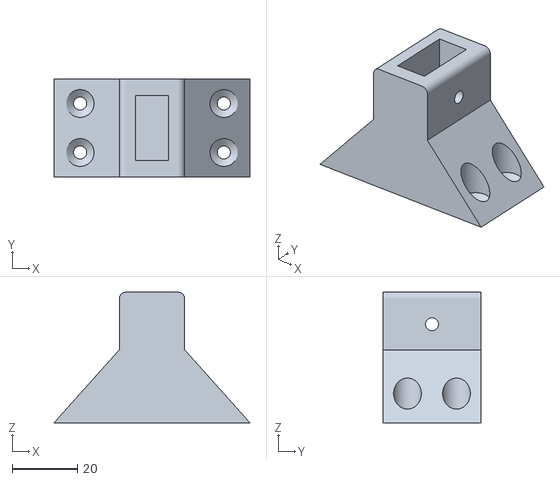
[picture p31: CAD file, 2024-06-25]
Mechanical Design/STL/Profile_Bracket.stl
60.0 x 30.0 x 40.0

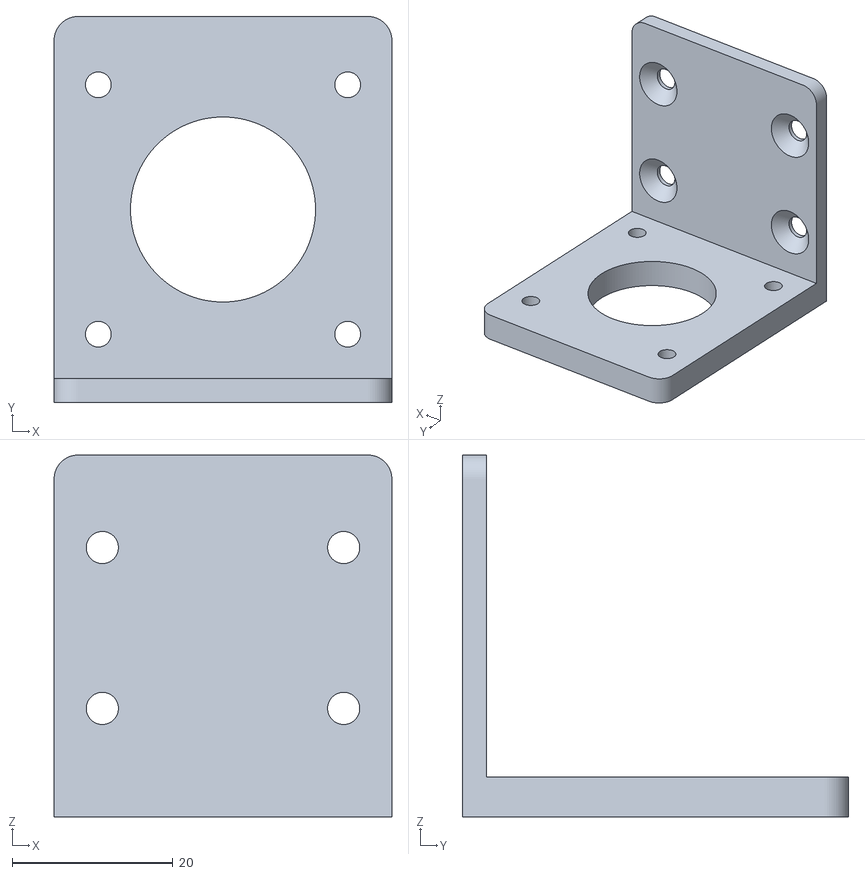
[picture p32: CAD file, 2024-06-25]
Mechanical Design/STL/Bed_Stepper_Motor_Bracket.stl
42.0 x 48.0 x 45.0

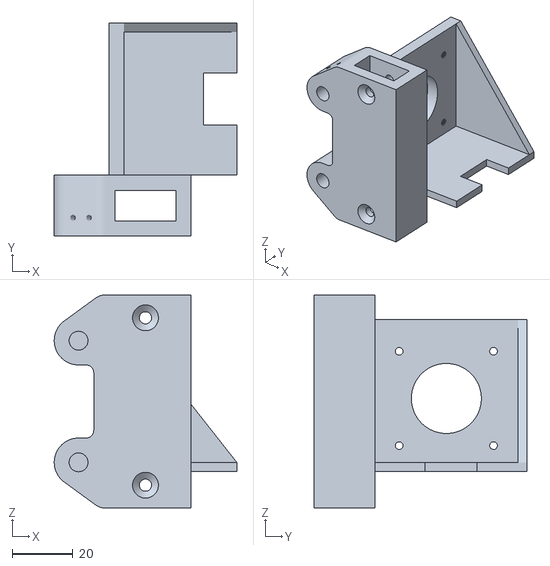
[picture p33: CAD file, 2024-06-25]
Mechanical Design/STL/Stepper_Motor_Mounting_Top_Plate.stl
60.0 x 70.0 x 70.0

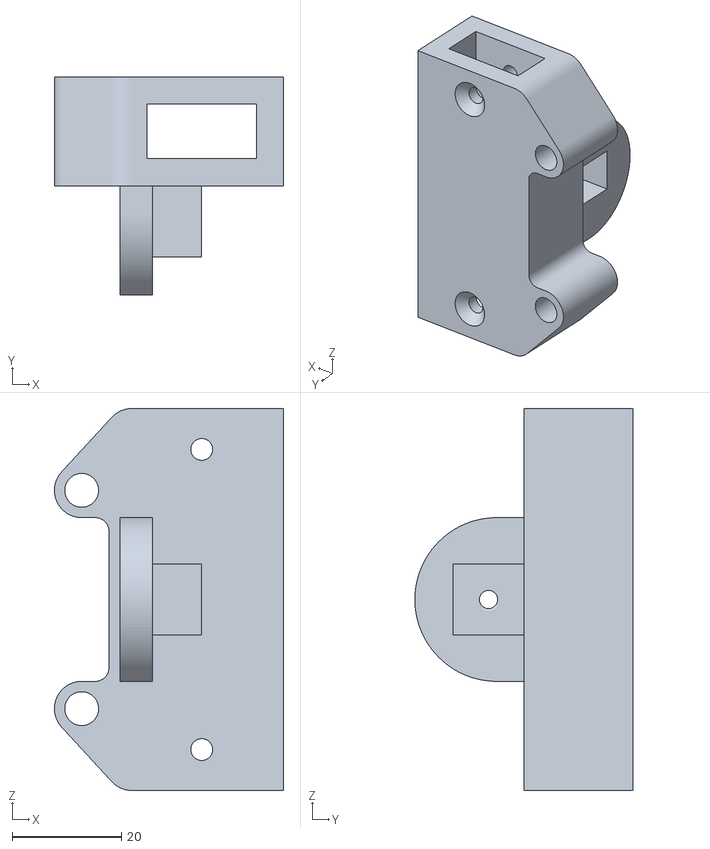
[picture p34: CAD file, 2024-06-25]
Mechanical Design/STL/Idler_Pulley_Mounting_Top_Plate.stl
42.0 x 40.0 x 70.0

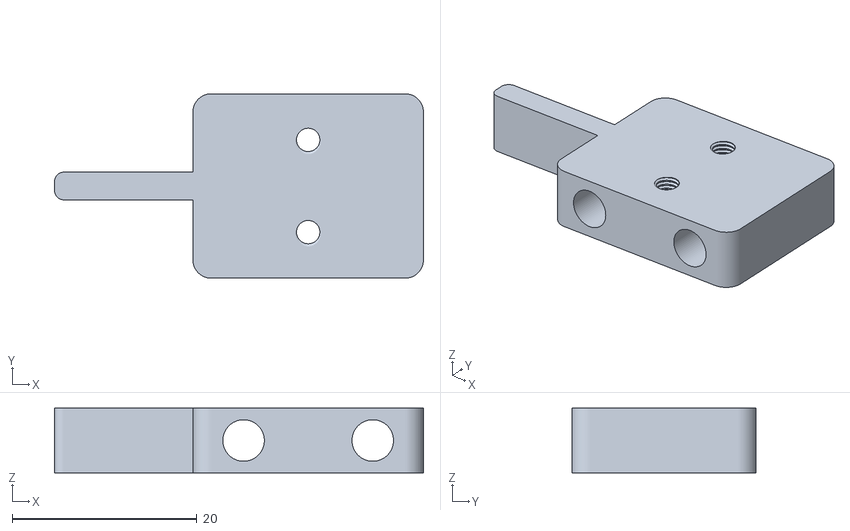
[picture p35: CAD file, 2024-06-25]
Mechanical Design/STL/Pen_Lift_Mechanism.stl
40.0 x 20.0 x 7.00

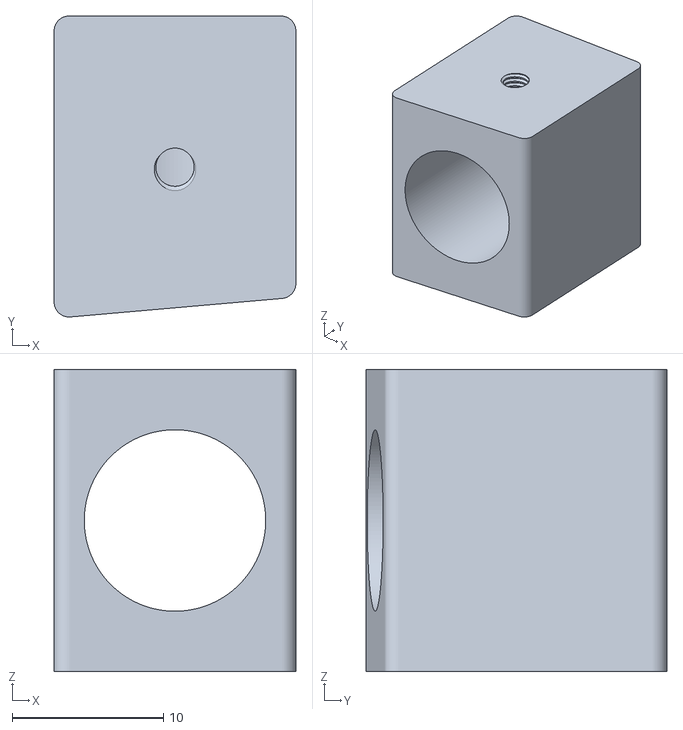
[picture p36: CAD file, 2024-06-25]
Mechanical Design/STL/Pen_Holder.stl
16.0 x 19.9 x 20.0

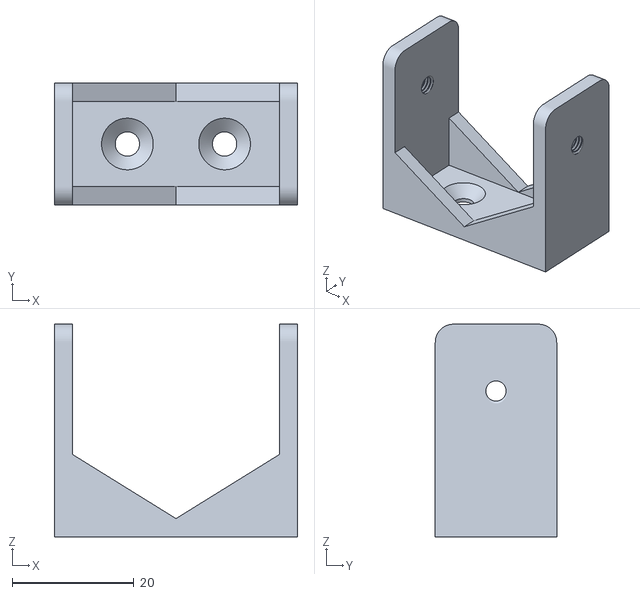
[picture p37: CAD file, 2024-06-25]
Mechanical Design/STL/Bed_Idler_Pulley_Bracket.stl
40.0 x 20.0 x 35.0

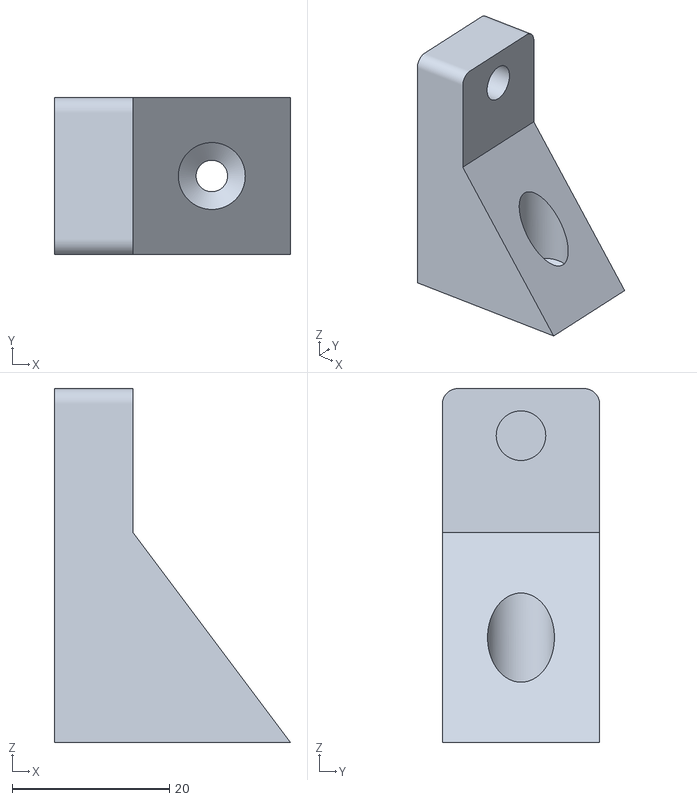
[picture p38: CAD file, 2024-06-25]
Mechanical Design/STL/Mounting_Block.stl
30.0 x 20.0 x 45.0

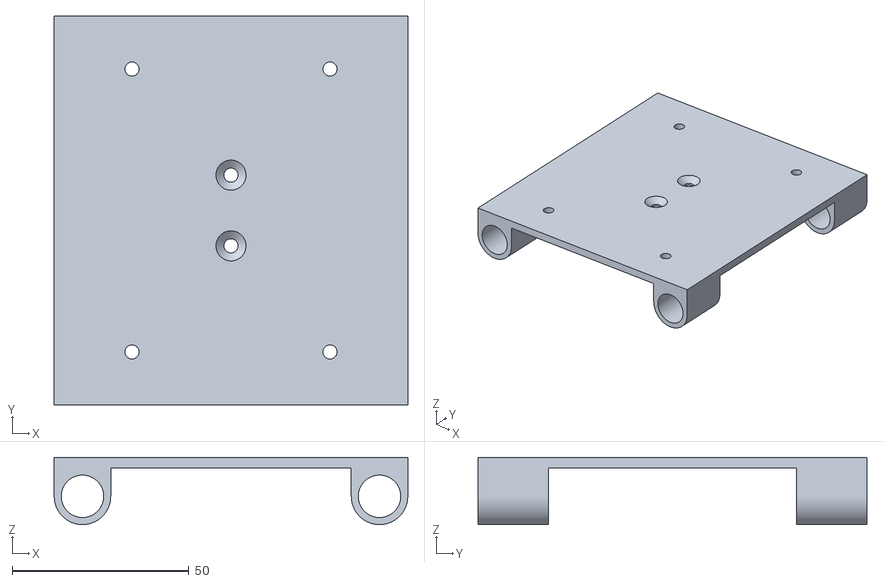
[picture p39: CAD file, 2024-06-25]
Mechanical Design/STL/Bed_Support.stl
100.0 x 110.0 x 19.0

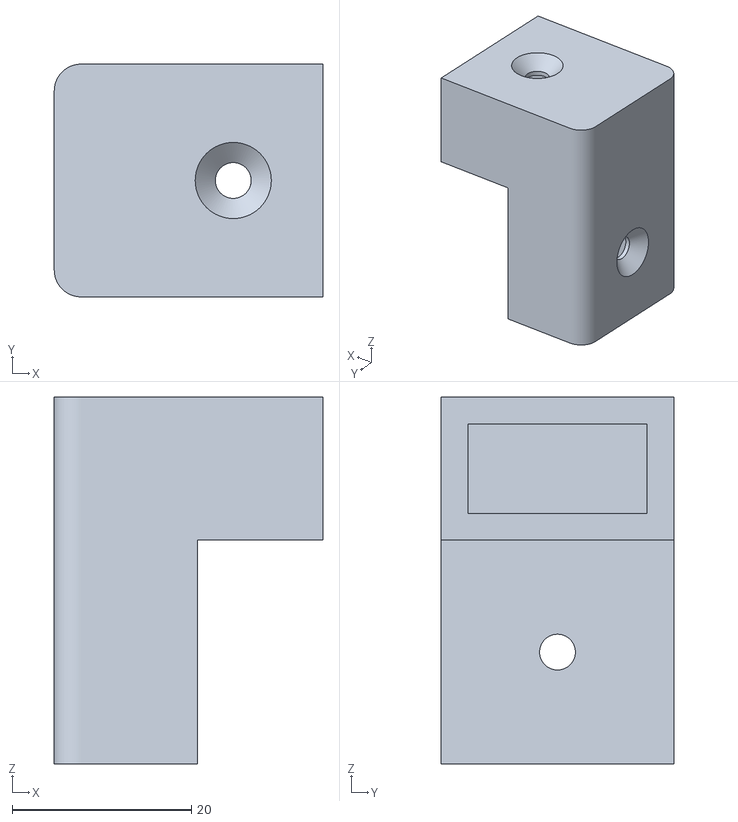
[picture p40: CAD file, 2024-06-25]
Mechanical Design/STL/Corner_L_Bracket.stl
30.0 x 26.0 x 41.0

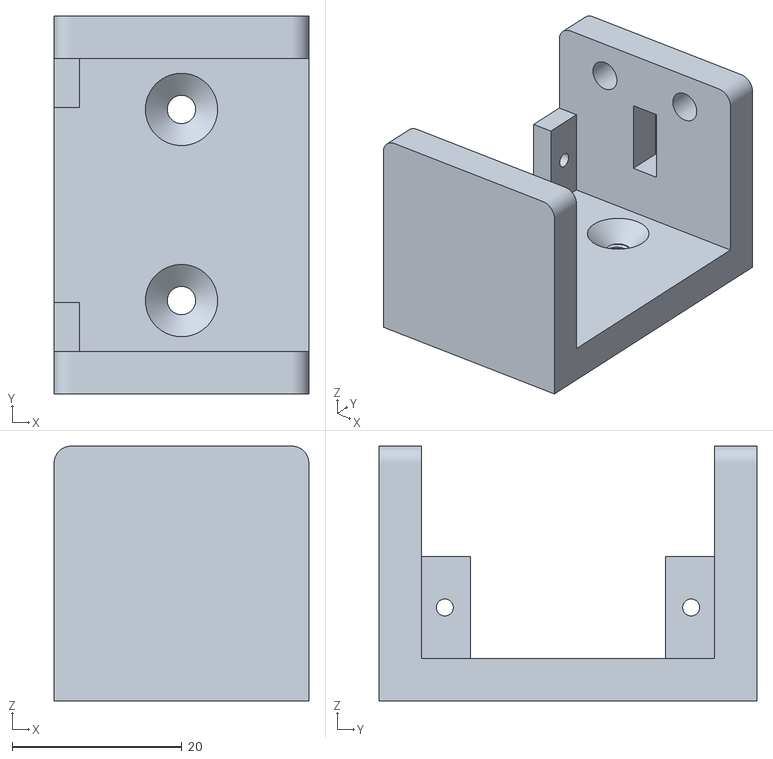
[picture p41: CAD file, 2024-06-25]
Mechanical Design/STL/Pen_Servo_Holder.stl
30.0 x 44.5 x 30.0

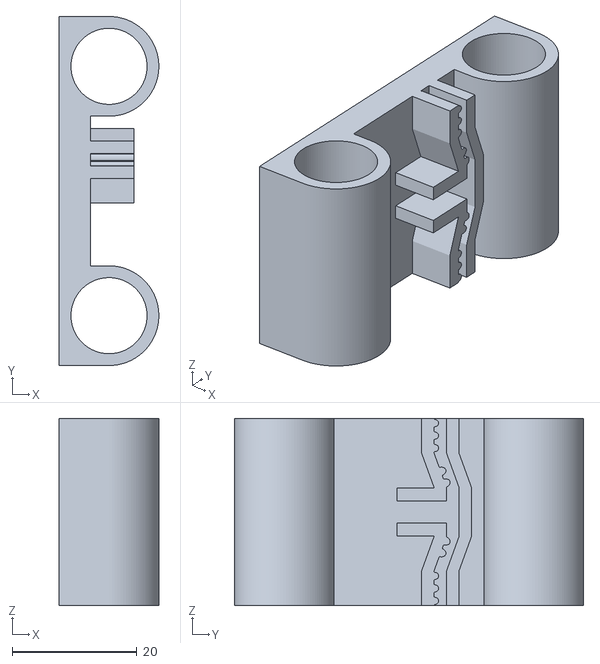
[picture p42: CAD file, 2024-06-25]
Mechanical Design/STL/Pen_Carriage.stl
16.0 x 56.0 x 30.0

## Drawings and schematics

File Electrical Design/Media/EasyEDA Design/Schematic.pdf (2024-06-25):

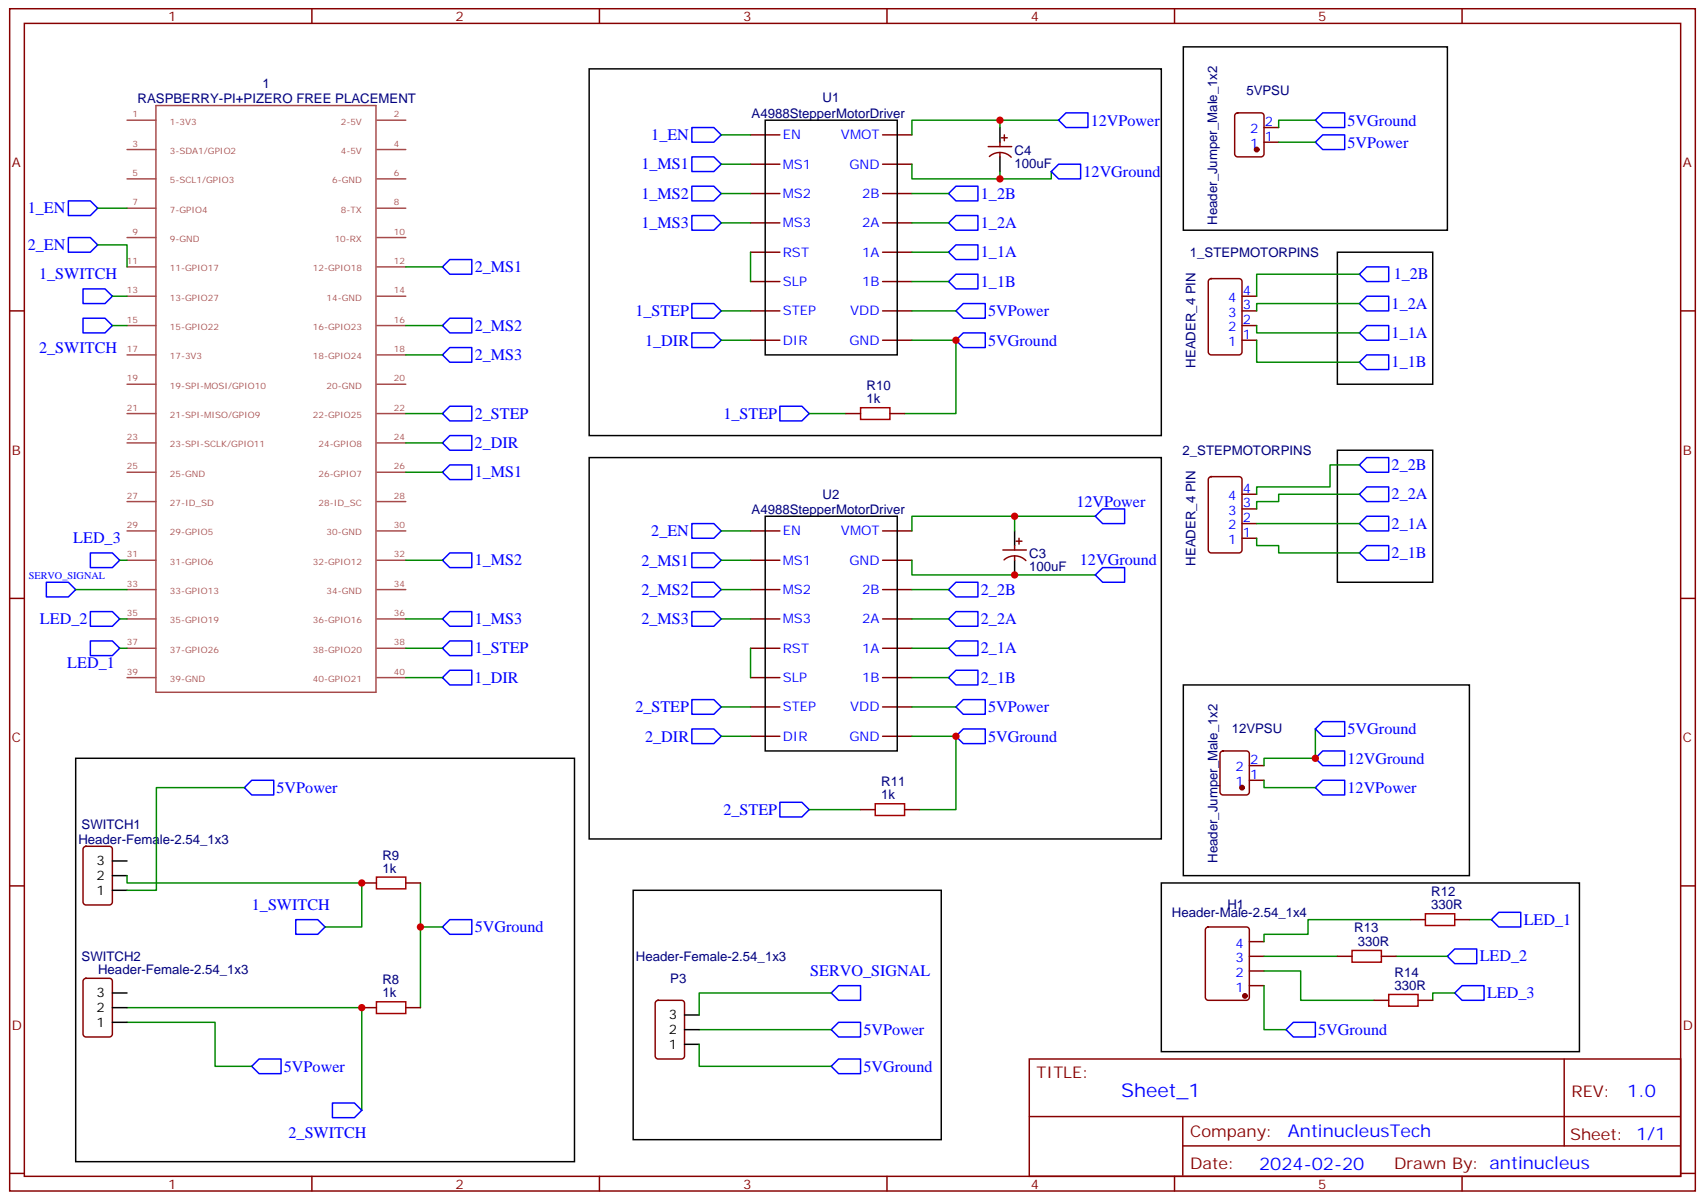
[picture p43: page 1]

RASPBERRY-PI+PIZERO FREE PLACEMENT
